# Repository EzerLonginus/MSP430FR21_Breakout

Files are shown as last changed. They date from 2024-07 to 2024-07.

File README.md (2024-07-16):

# MSP430FR21_Breakout
Basic breakout for the MSP430FR2111 chip

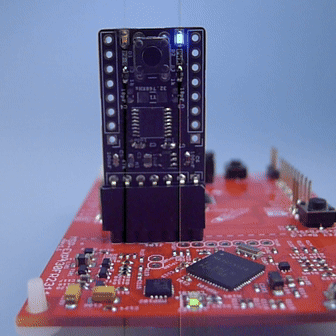
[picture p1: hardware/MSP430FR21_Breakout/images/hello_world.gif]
Hello World


## Description

This board is a simple breakout using the [MSP430FR2111](www.ti.com/lit/ds/symlink/msp430fr2111.pdf) chip.  All the pins of the chip are broken out into separate headers.  There is an additional header on the top of the board to allow for plugging directly into the MSP-EXP430FR2311 evaluation board to upload code.  The breakout can accept 5V through the onboard regulator, or 3.3V directly.  There is a reset and onboard power indication LED. There is also a slot for a 32.768kHz clock and onboard LED connected directly to P2.0, for testing.  

### Front
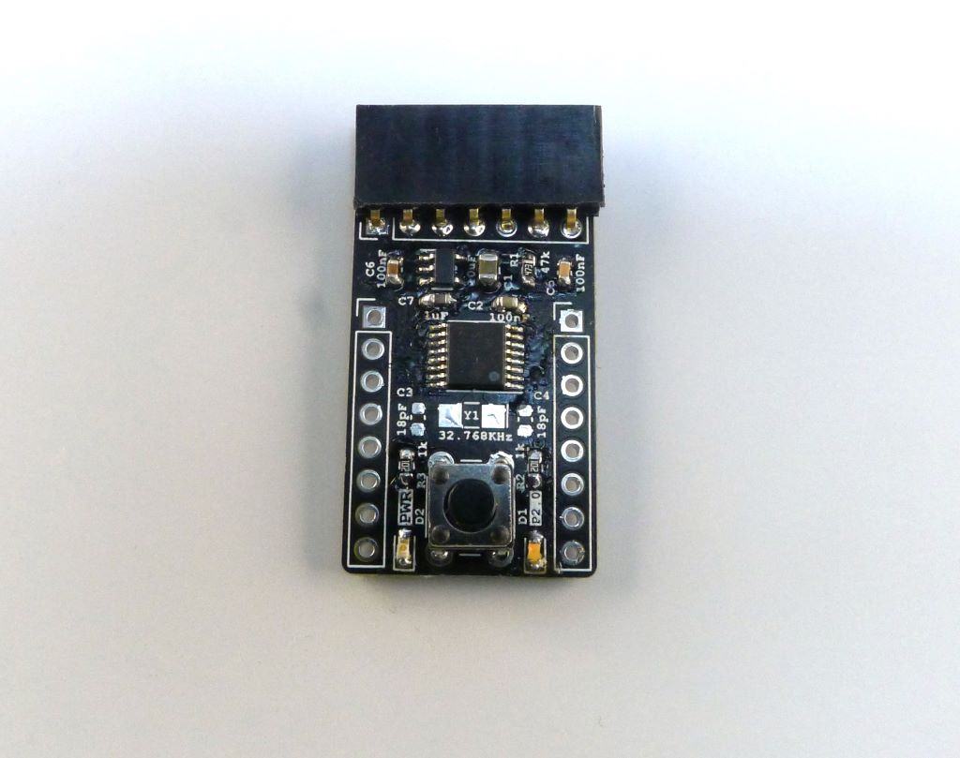
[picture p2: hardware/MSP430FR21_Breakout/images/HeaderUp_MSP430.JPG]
Front

### Back
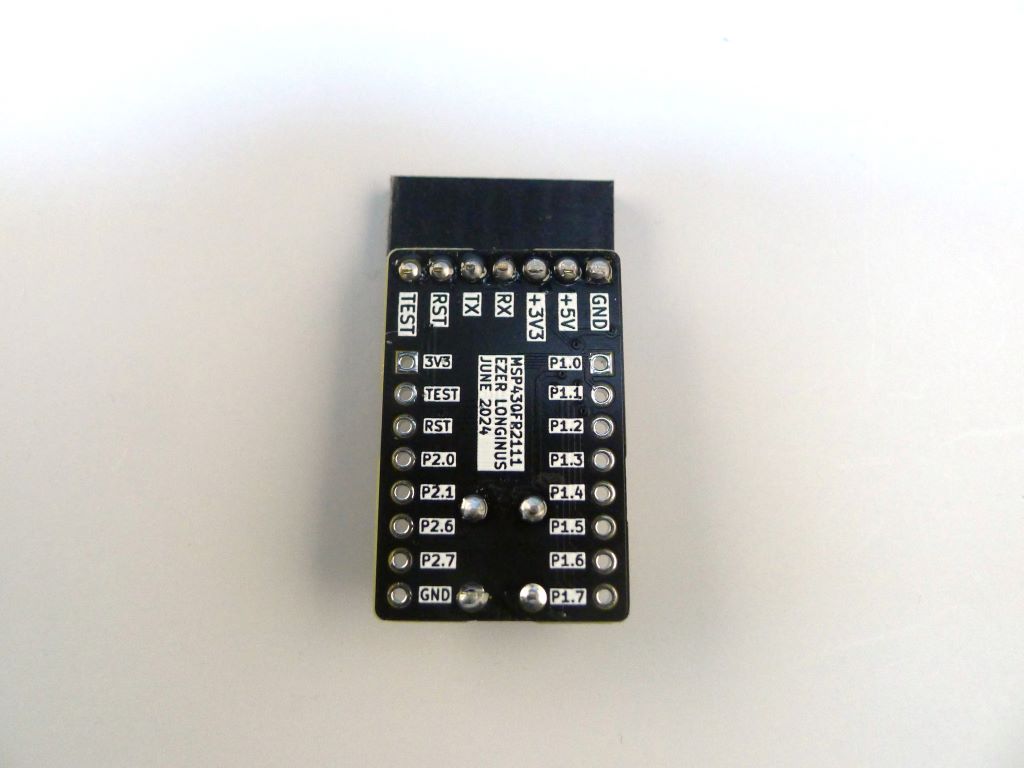
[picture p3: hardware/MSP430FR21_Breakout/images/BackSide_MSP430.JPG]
Back


## Purpose
I was looking to try out some development on the MSP430 series, slightly beyond the launch pads, and found a fairly [inexpensive chip](https://www.lcsc.com/product-detail/Microcontrollers-MCU-MPU-SOC_Texas-Instruments-MSP430FR2111IPW16_C1340043.html) to try to develop for.
I did make a slight error on the board that was ordered, which called out for 100nF capacitor on the reset line.  This actually needs to be 1nF, and has been fixed in the susequent gerber and design files.  Otherwise, the board basic goal has been achieved, and I'll continue to play around with the TI chip and architecture in the coming months to see what that is like.

## Schematic
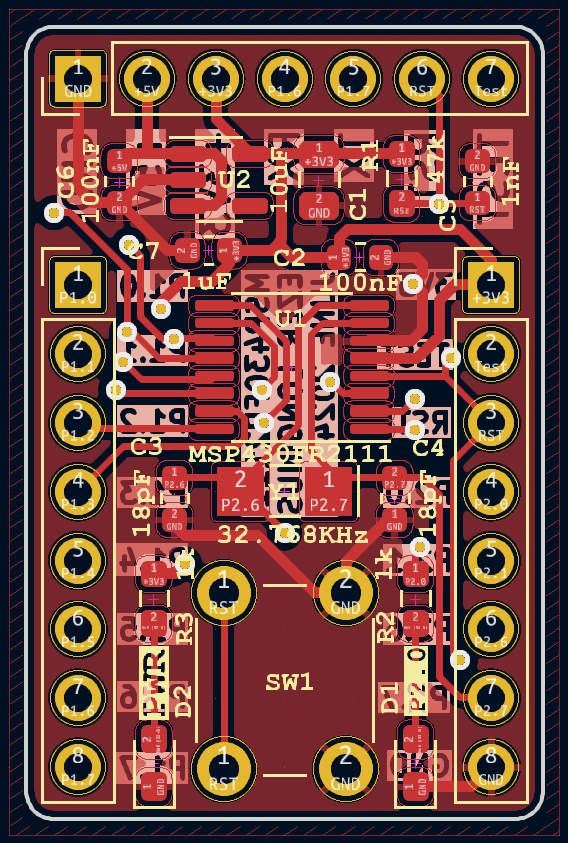
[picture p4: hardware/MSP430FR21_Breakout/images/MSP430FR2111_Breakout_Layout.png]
MSP430FR2111 Schematic

## Layout
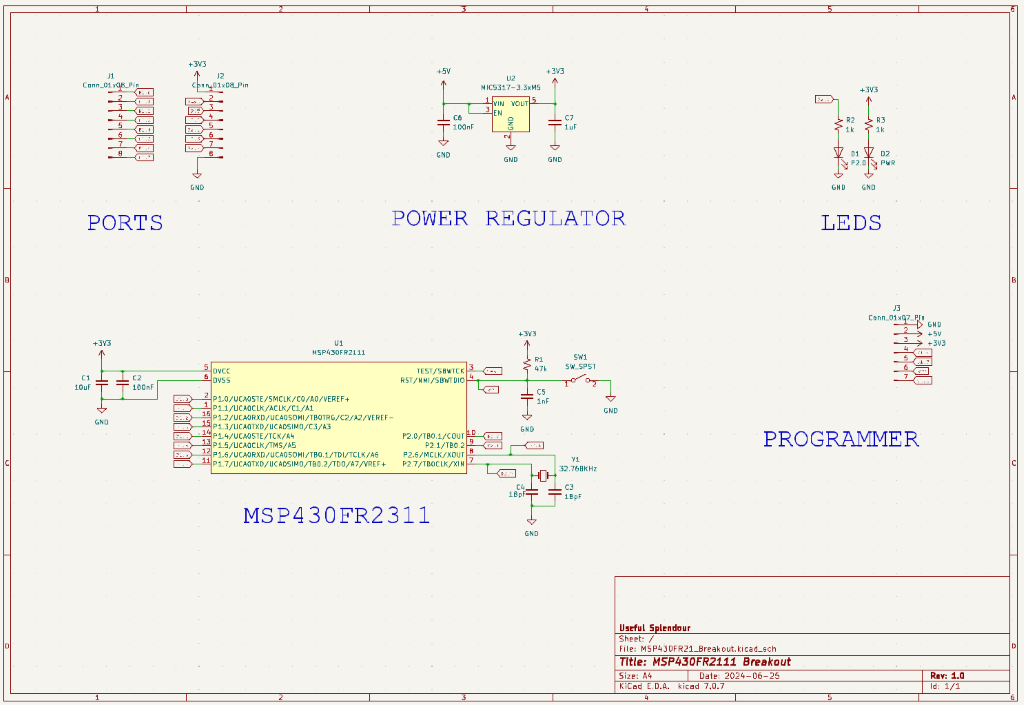
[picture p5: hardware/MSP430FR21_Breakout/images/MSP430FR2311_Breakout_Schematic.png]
Metronome Layout


## Updates & Fixes
### Version 1
* Continue testing functionality of board and breakout
* Add some test code for the breakout
* Updated Reset capacitor or 1nF




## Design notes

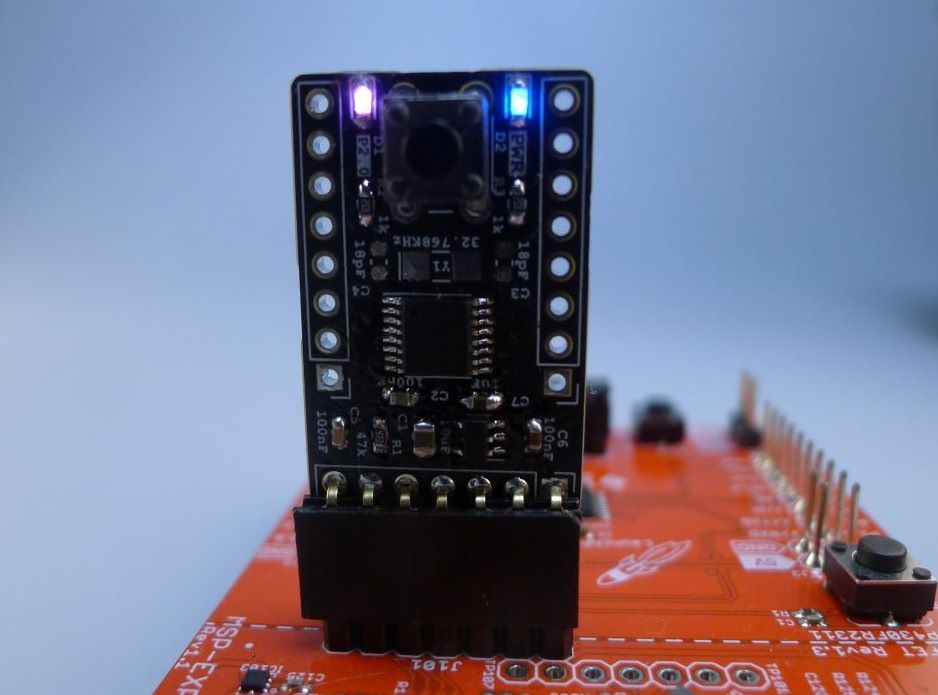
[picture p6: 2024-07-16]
hardware/MSP430FR21_Breakout/images/Programmer_MSP430_V02.JPG

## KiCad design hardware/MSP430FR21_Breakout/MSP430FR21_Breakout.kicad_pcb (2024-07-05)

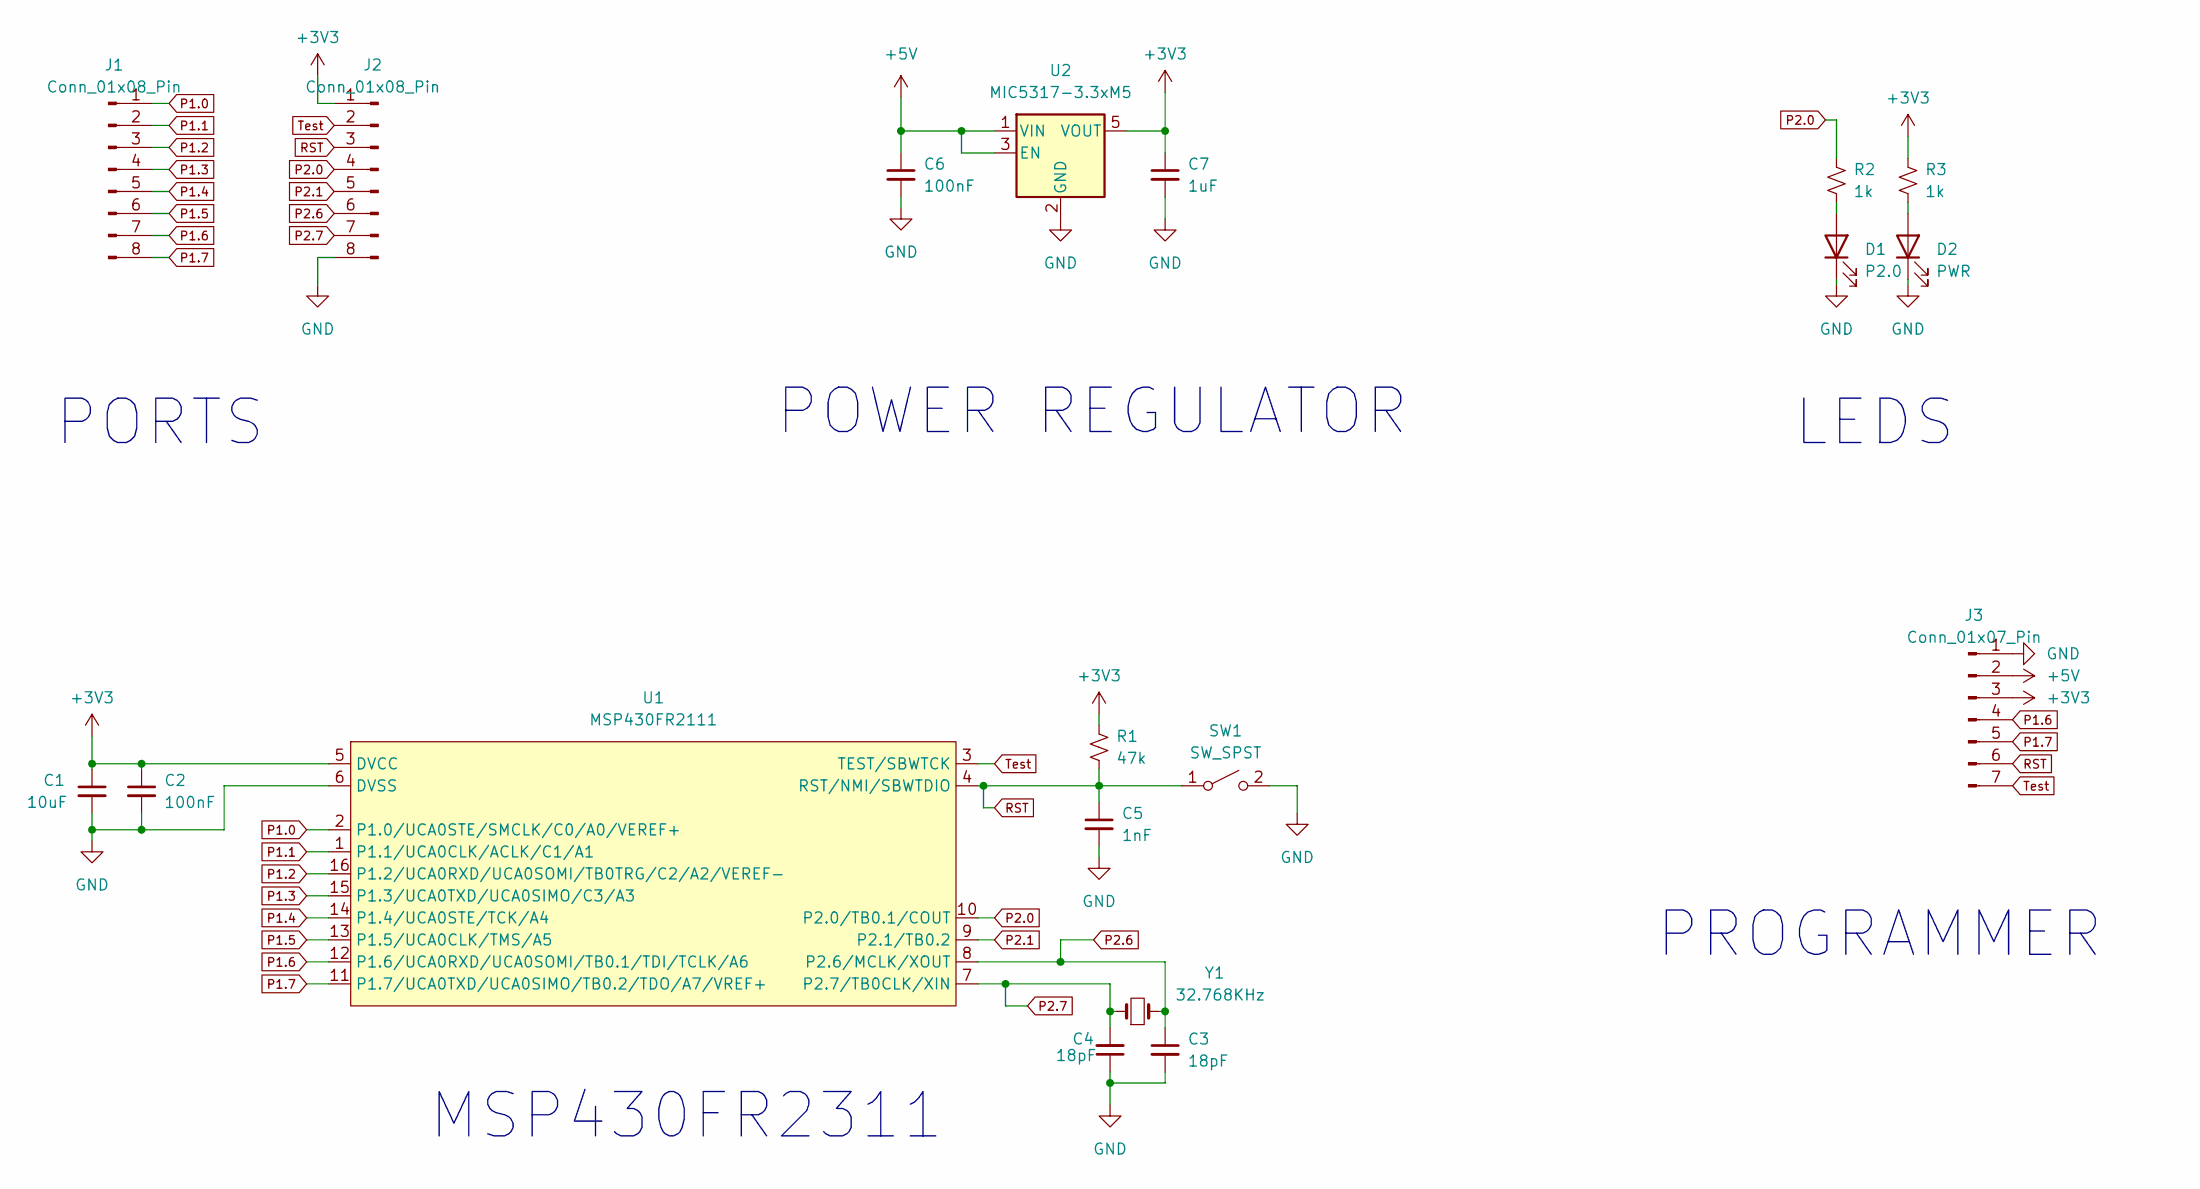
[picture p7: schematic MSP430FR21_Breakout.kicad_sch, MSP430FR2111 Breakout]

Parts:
C1: 10uF; C_0805_2012Metric
C2, C6: 100nF; C_0603_1608Metric
C3, C4: 18pF; C_0603_1608Metric
C5: 1nF; C_0603_1608Metric
C7: 1uF; C_0603_1608Metric
D1: P2.0; LED_0603_1608Metric_Pad1.05x0.95mm_HandSolder
D2: PWR; LED_0603_1608Metric_Pad1.05x0.95mm_HandSolder
J1, J2: Conn_01x08_Pin; PinHeader_1x08_P2.54mm_Vertical
J3: Conn_01x07_Pin; PinHeader_1x07_P2.54mm_Vertical
R1: 47k; R_0603_1608Metric_Pad0.98x0.95mm_HandSolder
R2, R3: 1k; R_0603_1608Metric_Pad0.98x0.95mm_HandSolder
SW1: SW_SPST; SW_PUSH_6mm
U1: MSP430FR2111; TSSOP-16_4.4x5mm_P0.65mm
U2: MIC5317-3.3xM5; SOT-23-5
Y1: 32.768KHz; Crystal_SMD_EuroQuartz_EQ161-2Pin_3.2x1.5mm_HandSoldering

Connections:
+3V3: C1.1, C2.1, C7.1, J2.1, J3.3, R1.1, R3.1, U1.5 (DVCC), U2.5 (VOUT)
+5V: C6.1, J3.2, U2.1 (VIN), U2.3 (EN)
GND: C1.2, C2.2, C3.2, C4.1, C5.2, C6.2, C7.2, D1.1 (K), D2.1 (K), J2.8, J3.1, SW1.2 (B), U1.6 (DVSS), U2.2 (GND)
unnamed: D1.2 (A), R2.2
unnamed: D2.2 (A), R3.2
P1.0: J1.1, U1.2 (P1.0/UCA0STE/SMCLK/C0/A0/VEREF+)
P1.1: J1.2, U1.1 (P1.1/UCA0CLK/ACLK/C1/A1)
P1.2: J1.3, U1.16 (P1.2/UCA0RXD/UCA0SOMI/TB0TRG/C2/A2/VERE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)
P1.3: J1.4, U1.15 (P1.3/UCA0TXD/UCA0SIMO/C3/A3)
P1.4: J1.5, U1.14 (P1.4/UCA0STE/TCK/A4)
P1.5: J1.6, U1.13 (P1.5/UCA0CLK/TMS/A5)
P1.6: J1.7, J3.4, U1.12 (P1.6/UCA0RXD/UCA0SOMI/TB0.1/TDI/TCLK/A6)
P1.7: J1.8, J3.5, U1.11 (P1.7/UCA0TXD/UCA0SIMO/TB0.2/TDO/A7/VREF+)
P2.0: J2.4, R2.1, U1.10 (P2.0/TB0.1/COUT)
P2.1: J2.5, U1.9 (P2.1/TB0.2)
P2.6: C3.1, J2.6, U1.8 (P2.6/MCLK/XOUT), Y1.2
P2.7: C4.2, J2.7, U1.7 (P2.7/TB0CLK/XIN), Y1.1
RST: C5.1, J2.3, J3.6, R1.2, SW1.1 (A), U1.4 (RST/NMI/SBWTDIO)
Test: J2.2, J3.7, U1.3 (TEST/SBWTCK)

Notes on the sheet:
LEDS
POWER REGULATOR
PROGRAMMER
PORTS
MSP430FR2311

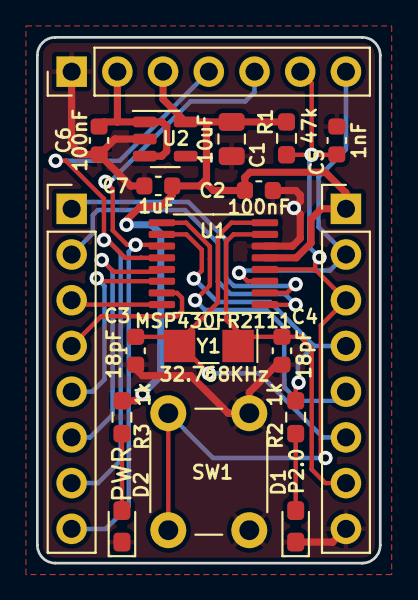
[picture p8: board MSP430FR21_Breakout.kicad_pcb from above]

Board: 2 copper layers, 19.1 x 29.2 mm, 19 parts (0 on the bottom side), 19 nets.

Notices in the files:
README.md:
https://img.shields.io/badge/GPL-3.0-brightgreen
